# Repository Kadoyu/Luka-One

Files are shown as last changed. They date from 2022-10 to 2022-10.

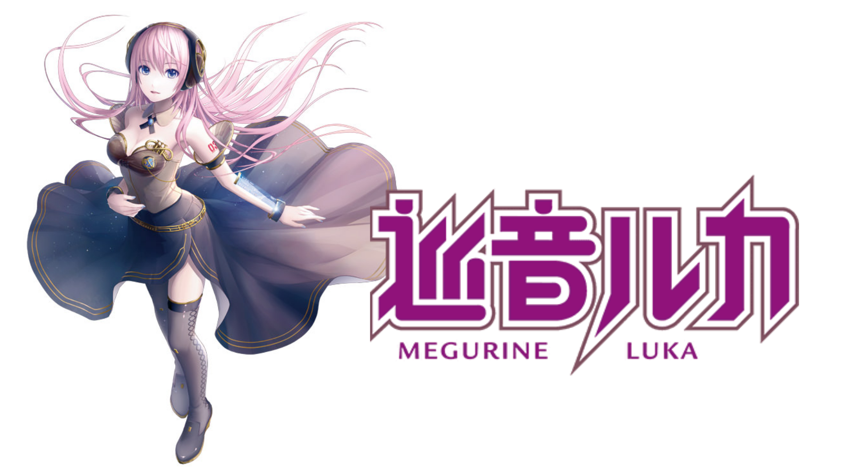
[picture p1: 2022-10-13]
asset/Luka One BottomSilk.png

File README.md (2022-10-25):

# 初音ミク Project DIVA MEGA39's+ 用コントローラー「Luka One」  
アーケードLikeなコントローラーです。  
**INFO・CONTACT [https://twitter.com/wakiwakkii](https://twitter.com/wakiwakkii)**　　

2022収穫祭出典品
## Features  
* Divaのアーケードをイメージした配置  
* GP2040を搭載しているため遅延が少ない  
* ★★1677万色に光る★★(理論値)  

## Usage  
ファームウェアは上側面のRESETボタンを２回押すとドライブとして認識されます。  
そこにUF2ファイルをコピペしてください。

Pico Fighting Board用のUF2ファイルを使用してね。
ここからダウンロードできます。
[https://github.com/FeralAI/GP2040/releases](https://github.com/FeralAI/GP2040/releases)

## License
This product is licensed [CC-BY](https://creativecommons.org/licenses/by/4.0/legalcode.txt).

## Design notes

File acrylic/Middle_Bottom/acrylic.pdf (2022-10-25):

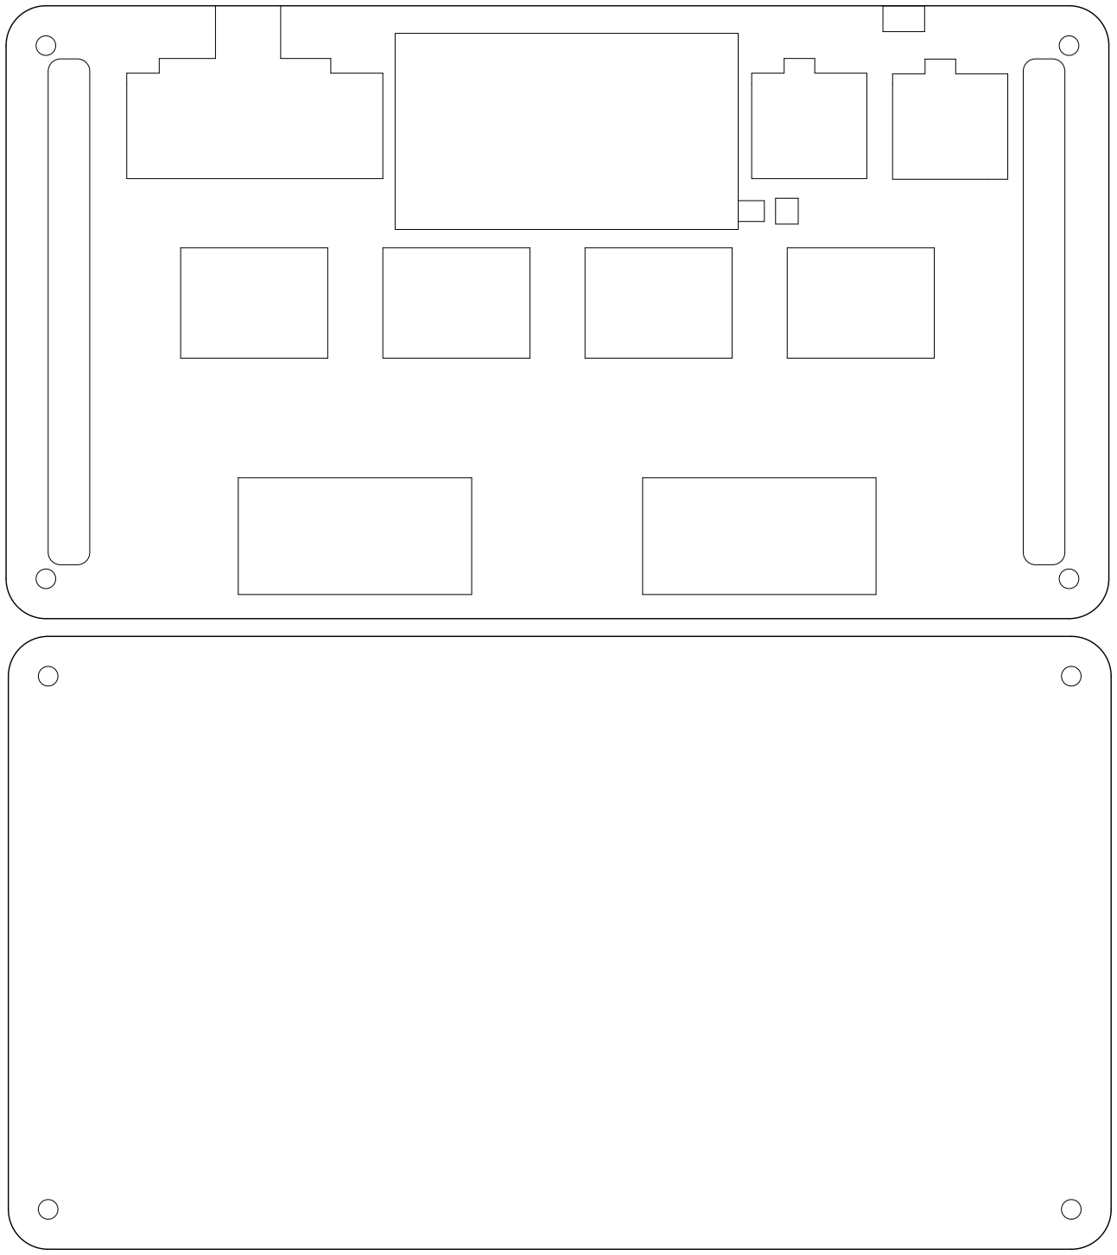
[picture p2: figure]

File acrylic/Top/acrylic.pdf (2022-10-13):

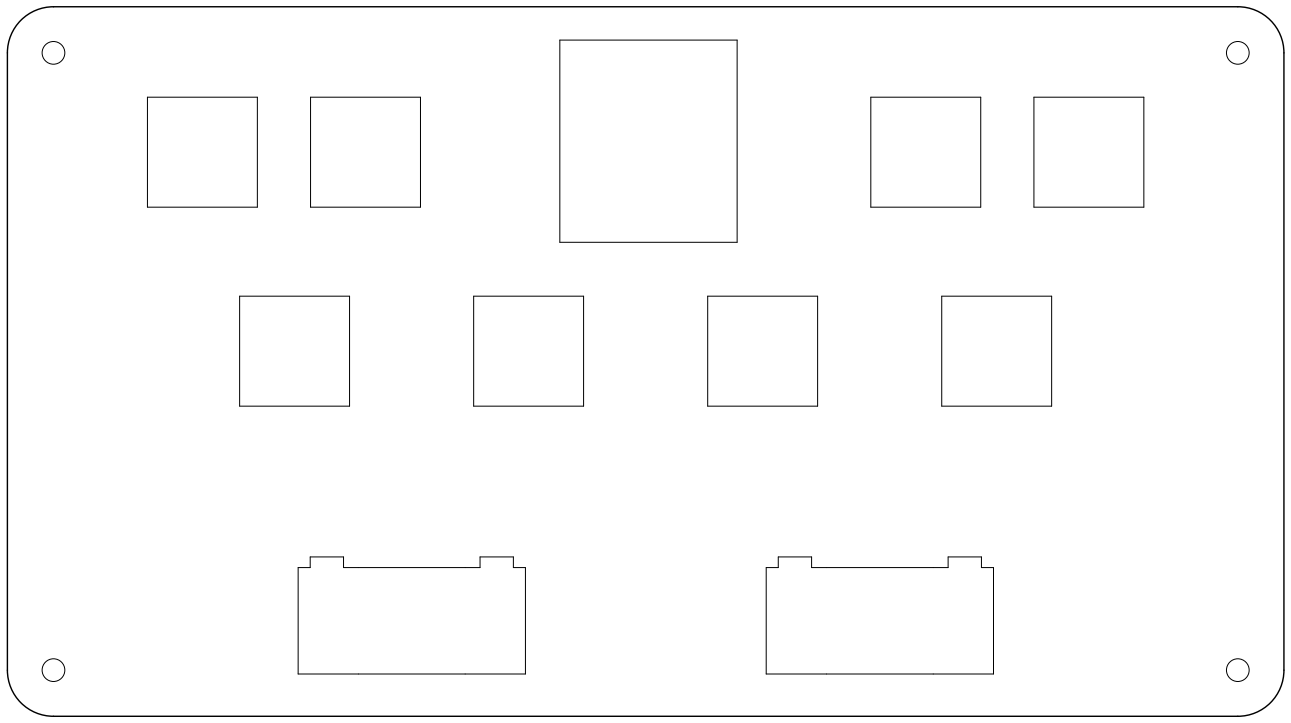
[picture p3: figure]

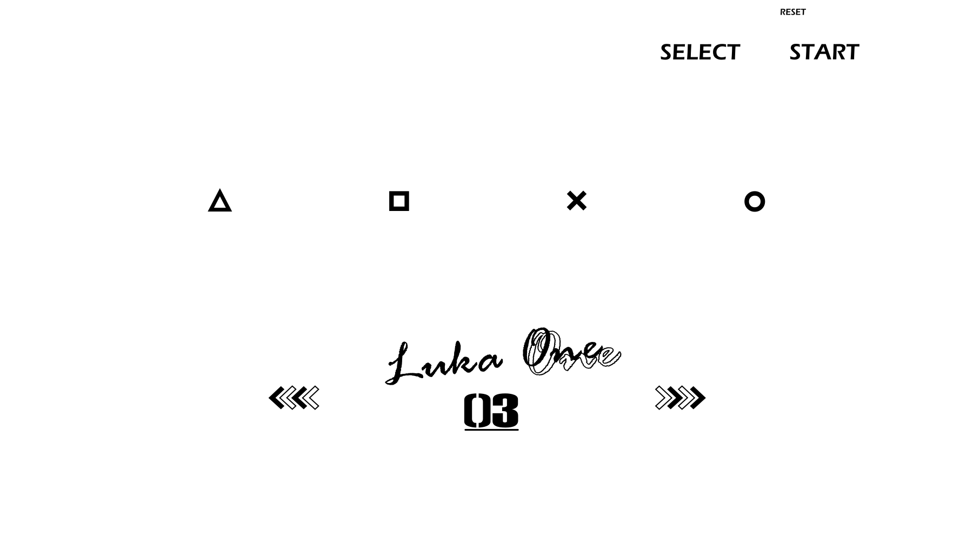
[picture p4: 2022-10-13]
asset/Luka One TopSilk.png

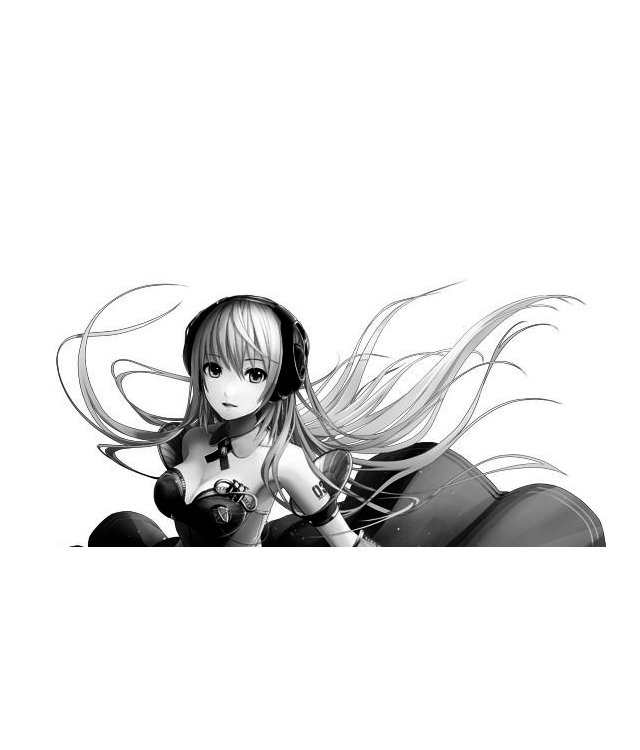
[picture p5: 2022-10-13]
asset/megurine luka.png

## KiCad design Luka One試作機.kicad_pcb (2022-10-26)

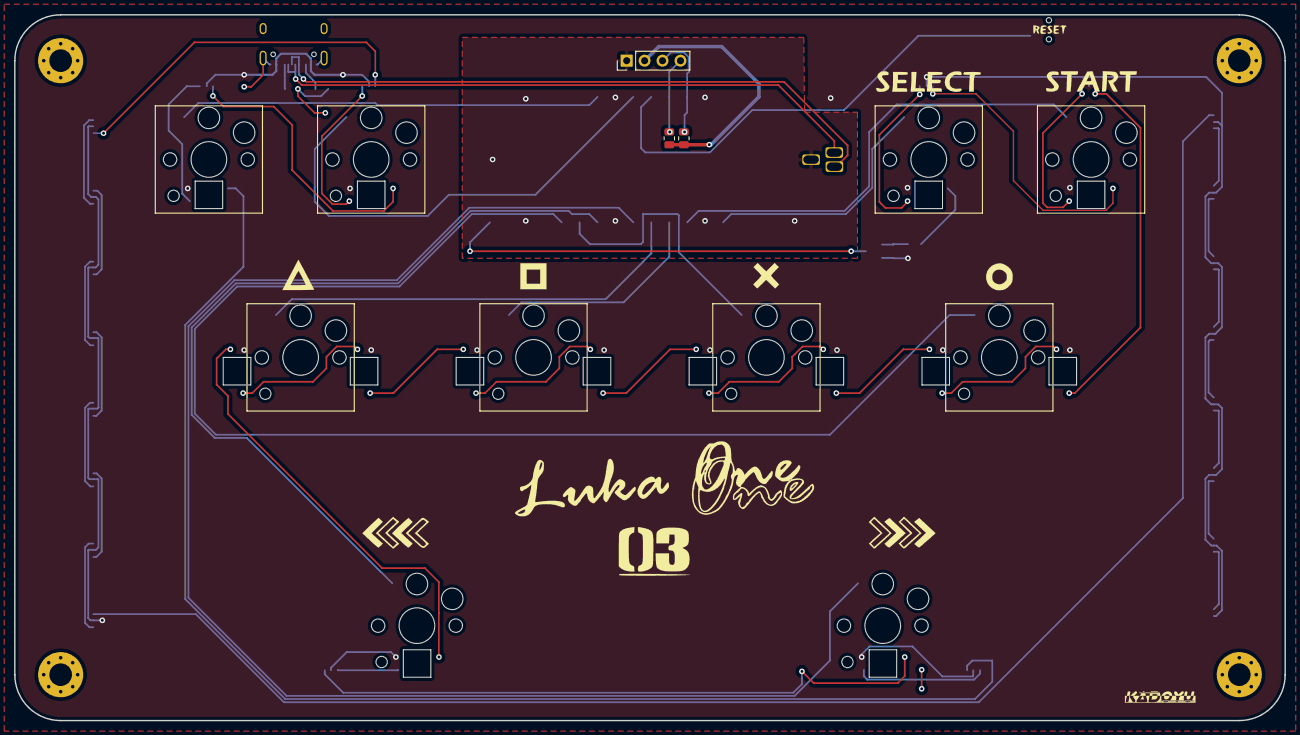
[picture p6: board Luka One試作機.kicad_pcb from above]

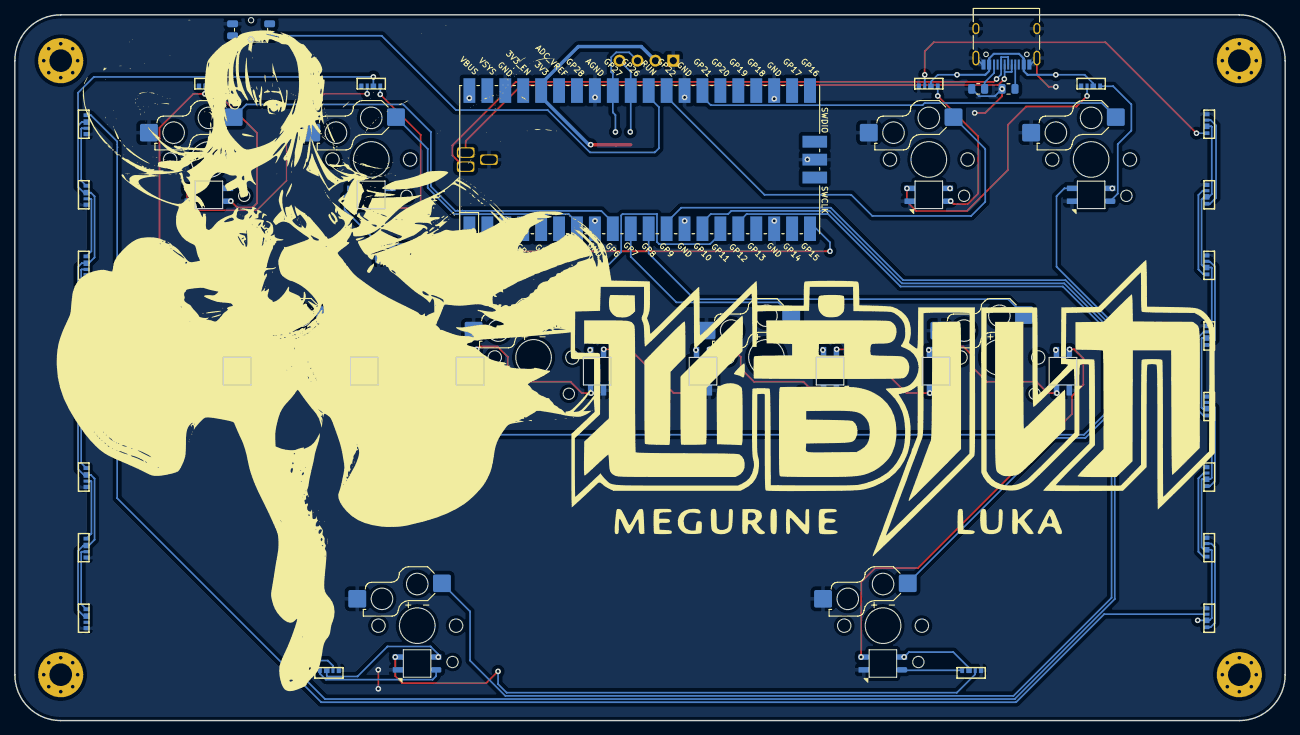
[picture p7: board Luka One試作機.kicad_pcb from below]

Board: 2 copper layers, 180.0 x 100.0 mm, 38 parts (29 on the bottom side), 33 nets.

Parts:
C1: 0.1uF; C_0805_2012Metric
J1: USB_C_Receptacle_USB2.0; USB_C_Receptacle_HRO_TYPE-C-31-M-12
J2: Conn_01x04_Male; PinHeader_1x04_P2.54mm_Vertical
Kailh PG1350, Kailh PG1351, Kailh PG1352, Kailh PG1353: Choc; SW_Hotswap_Kailh_Choc_V1V2_1.50u
Kailh PG1354, Kailh PG1354#2: Choc; Kailh-PG1350-2u
LED, LED1, LED2, LED3, LED4, LED5, LED6, LED7, LED8, LED9, LED10, LED11, LED12, LED13, LED14, LED14#2, LED14#3, LED14#4, LED14#5, LED14#6, LED14#7: WS2812B-4020
LED#2: WS2812B-4020
R1, R2: 5.1k; R_0805_2012Metric
R3, R4: 4.7k; R_0805_2012Metric
R5: 330; R_0805_2012Metric
U1: Pico; RPi_Pico_SMD_TH
U2: SN74LV1T34DBV; SOT-23-5

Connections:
/3V3: J2.2, R3.1, R4.1, U1.36 (3V3)
/A: Kailh PG1352.1, U1.15 (GPIO11)
/B: Kailh PG1353.1, U1.16 (GPIO12)
/LB: Kailh PG1354.1, U1.14 (GPIO10)
/RB: Kailh PG1354#2.1, U1.12 (GPIO9)
/RGB: U1.20 (GPIO15), U2.2 (A)
/SCL: J2.3, R3.2, U1.32 (GPIO27_ADC1)
/SDA: J2.4, R4.2, U1.31 (GPIO26_ADC0)
/TP2: J1.A7 (D-), J1.B7 (D-), U1.TP2
/TP3: J1.A6 (D+), J1.B6 (D+), U1.TP3
/X: Kailh PG1351.1, U1.10 (GPIO7)
/Y: Kailh PG1350.1, U1.11 (GPIO8)
GND: C1.1, J1.A1 (GND), J1.A12 (GND), J1.B1 (GND), J1.B12 (GND), J1.S1 (SHIELD), J2.1, Kailh PG1350.2, Kailh PG1351.2, Kailh PG1352.2, Kailh PG1353.2, Kailh PG1354.2, Kailh PG1354#2.2, LED.4, LED1.4, LED2.4, LED3.4, LED4.4, LED5.4, LED6.4, LED7.4, LED8.4, LED9.4, LED10.4, LED11.4, LED12.4, LED13.4, LED14.4, LED14#2.4, LED14#3.4, LED14#4.4, LED14#5.4, LED14#6.4, LED14#7.4, LED#2.4, R1.2, R2.2, U1.3 (GND), U1.8 (GND), U1.13 (GND), U1.18 (GND), U1.23 (GND), U1.28 (GND), U1.33 (AGND), U1.38 (GND), U1.42 (GND), U1.TP1, U2.3 (GND)
unnamed: J1.A5 (CC1), R2.1
unnamed: J1.B5 (CC2), R1.1
unnamed: R5.1, U2.4 (Y)
RGB_DATA_5V_20: LED14#4.3, LED#2.1
RGB_DATA_5V_21: LED1.1, LED#2.3
RGB_DATA_5V_22: LED1.3, LED2.1
RGB_DATA_5V_23: LED2.3, LED3.1
RGB_DATA_5V_24: LED3.3, LED4.1
RGB_DATA_5V_25: LED4.3, LED5.1
RGB_DATA_5V_26: LED5.3, LED6.1
RGB_DATA_5V_27: LED6.3, LED7.1
RGB_DATA_5V_28: LED7.3, LED14#6.1
RGB_DATA_5V_29: LED13.1, LED14#6.3
RGB_DATA_5V_30: LED12.1, LED13.3
RGB_DATA_5V_31: LED11.1, LED12.3
RGB_DATA_5V_32: LED10.1, LED11.3
RGB_DATA_5V_33: LED9.1, LED10.3
RGB_DATA_5V_34: LED8.1, LED9.3
RGB_DATA_5V_35: LED.1, LED8.3
VBUS: C1.2, J1.A4 (VBUS), J1.A9 (VBUS), J1.B4 (VBUS), J1.B9 (VBUS), LED.2, LED1.2, LED2.2, LED3.2, LED4.2, LED5.2, LED6.2, LED7.2, LED8.2, LED9.2, LED10.2, LED11.2, LED12.2, LED13.2, LED14.2, LED14#2.2, LED14#3.2, LED14#4.2, LED14#5.2, LED14#6.2, LED14#7.2, LED#2.2, U1.40 (VBUS), U2.5 (VCC)
